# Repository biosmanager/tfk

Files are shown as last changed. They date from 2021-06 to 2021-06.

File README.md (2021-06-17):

# tfk - The F(ine|fancy|inal) Keyboard

This is a work in progress collection of open-source high-end keyboard PCBs. 

**Features**:

-   Compatible with QMK firmware and VIA
-   Hot-swap sockets
-   Per-key RGB lighting and RGB backlight
-   USB-C
-   Overvoltage, overcurrent and ESD protection
-   (All powered by STM32 microcontrollers)

> **NOTE:**  Due to the current global chip crisis I decided to use AVR based microcontrollers in the first revisions which are easier to obtain.

## Keyboards

|Status | Name  | Size | # of keys | Description | MCU | Compatible cases (intended) |
|---| ----- | ---- | --- | ---|-----|---|
| <span style="color: green">Active</span> | tfk21-avr | 20% | 21 | Numpad with extra row | ATmega32U4 | [KPRepublic Cospad cases](https://kprepublic.com/collections/cospad-xd24) |
| <span style="color: red">On hold</span>  | tfk21 | 20% | 21 | Numpad with extra row | STM32F072  | [KPRepublic Cospad cases](https://kprepublic.com/collections/cospad-xd24) |
| <span style="color: red">On hold</span>  | tfk84 | 75% | 84 | More compact than a TKL | STM32F303  | [KPRepublic XD84 cases](https://kprepublic.com/collections/xd84) |

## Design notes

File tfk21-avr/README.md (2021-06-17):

# tfk21-avr

21 key hot-swap RGB numpad with extra row on top. Uses Microchip ATmega32U4-AU microcontroller. 
All footprints should be suitable for hand soldering.

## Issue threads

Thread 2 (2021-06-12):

Update TQFP-48 thermal vias footprint

biosmanager, 2021-06-12:
The default thermal via sizes are too small for JLCPCB.

biosmanager, 2021-06-17:
Not necessary in 4 layer layout.

Closed 2021-06-17.

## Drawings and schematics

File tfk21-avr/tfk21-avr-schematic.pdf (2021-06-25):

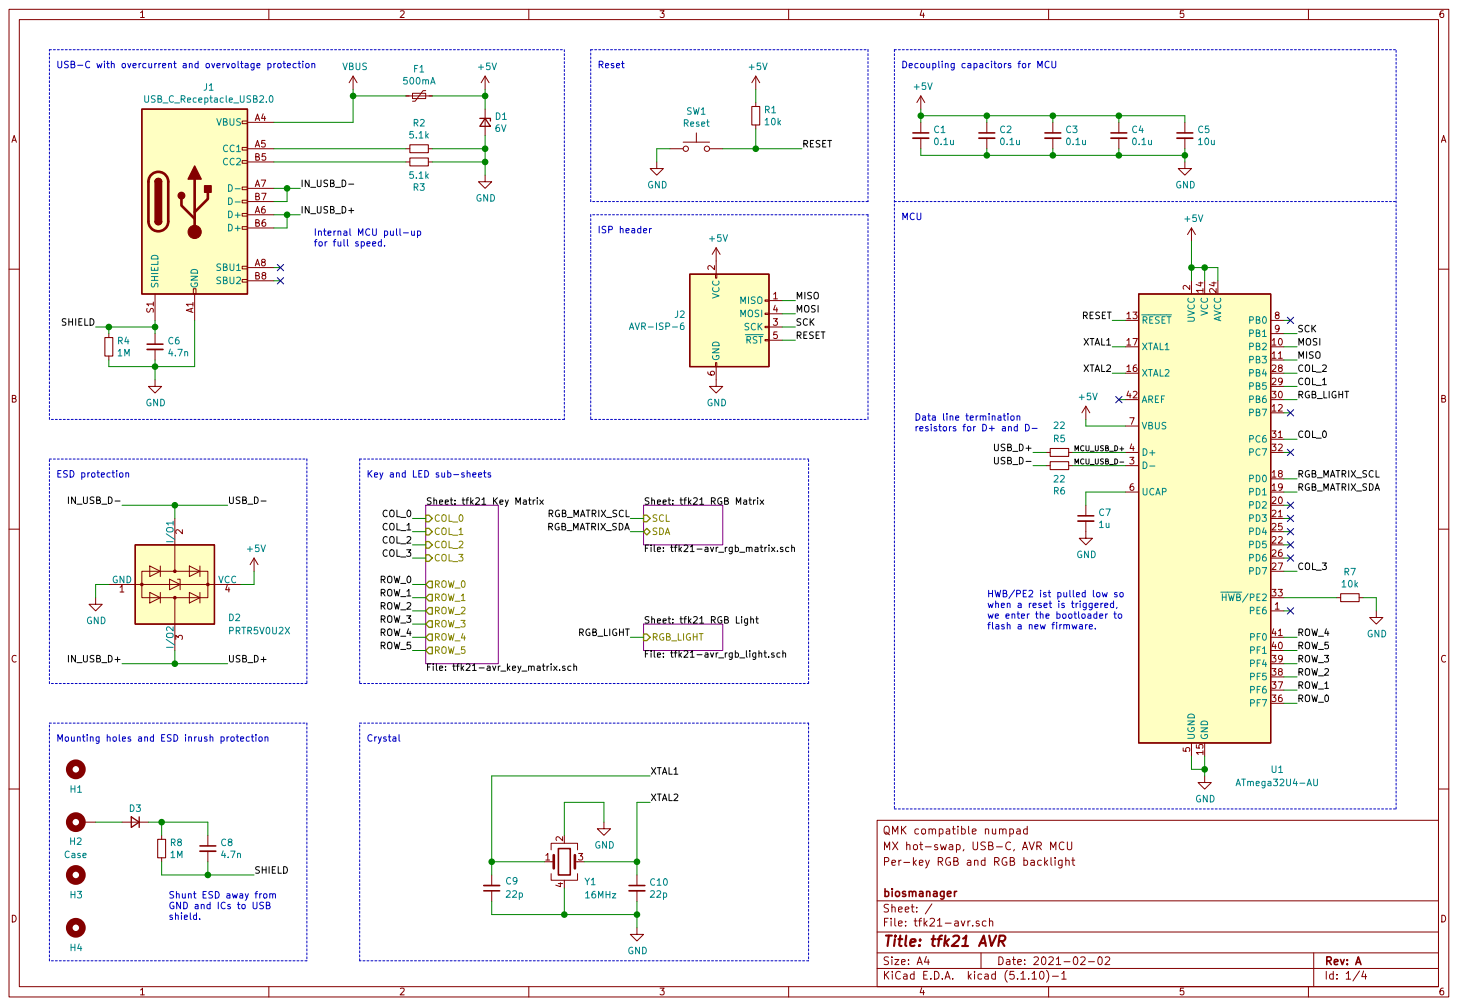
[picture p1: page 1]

USB-C with overcurrent and overvoltage protection

Decoupling capacitors for MCU

Internal MCU pull-up
for full speed.

2 SCK 3 MOSI 4 RST 5 GND

2 PD2 20 PD3 21 PD5 22 AVCC 24 PD4 25 PD6 26 PD7 27 PB4 28 PB5 29 D- 3 PB6 30 PC6 31 PC7 32 HWB/PE2 33 PF7 36 PF6 37 PF5 38 PF4 39 D+ 4 PF1 40 PF0 41 AREF 42 UGND

Key and LED sub-sheets

File: tfk21-avr_rgb_light.sch RGB_LIGHT Sheet: tfk21 Key Matrix

HWB/PE2 ist pulled low so
when a reset is triggered, we enter the bootloader to

QMK compatible numpad
MX hot-swap, USB-C, AVR MCU
Per-key RGB and RGB backlight

File: tfk21-avr.sch Sheet: / biosmanager

Shunt ESD away from GND and ICs to USB shield.

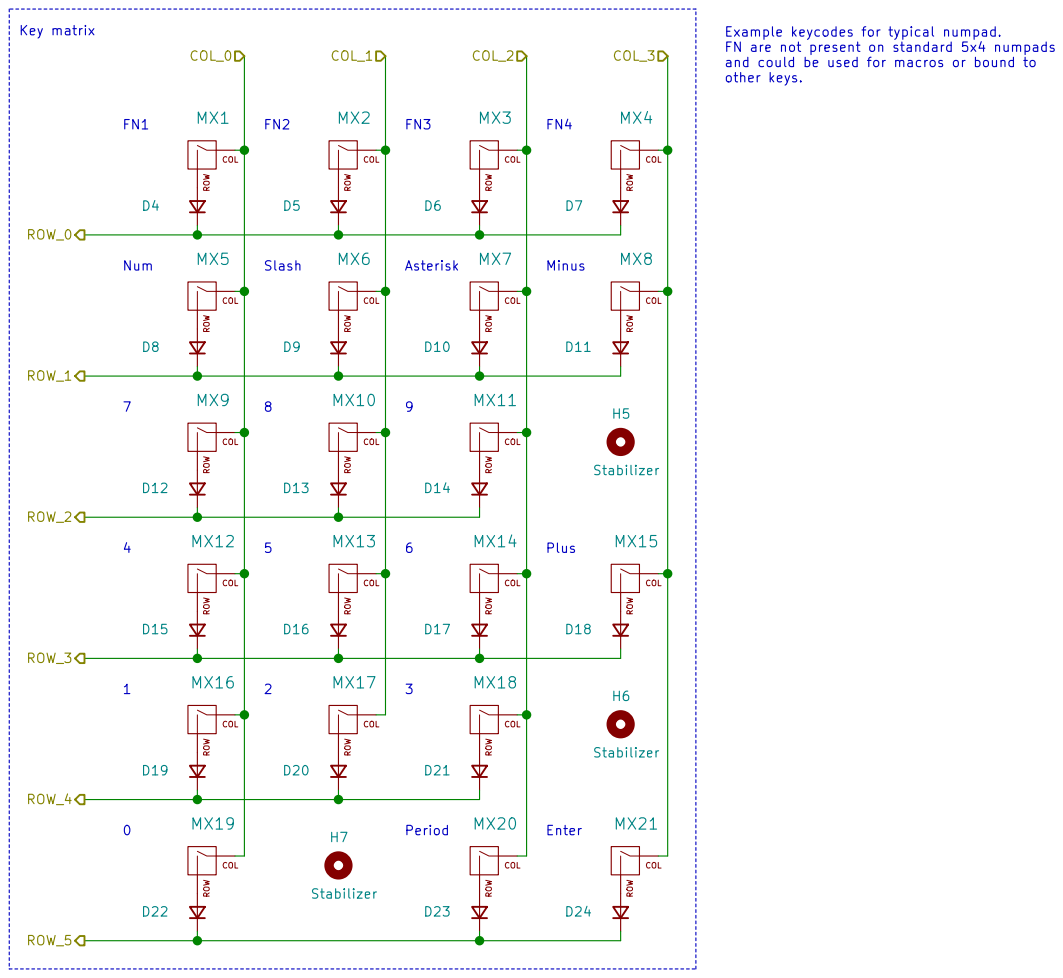
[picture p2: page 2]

Example keycodes for typical numpad.
FN are not present on standard 5x4 numpads and could be used for macros or bound to
COL ROW MX4

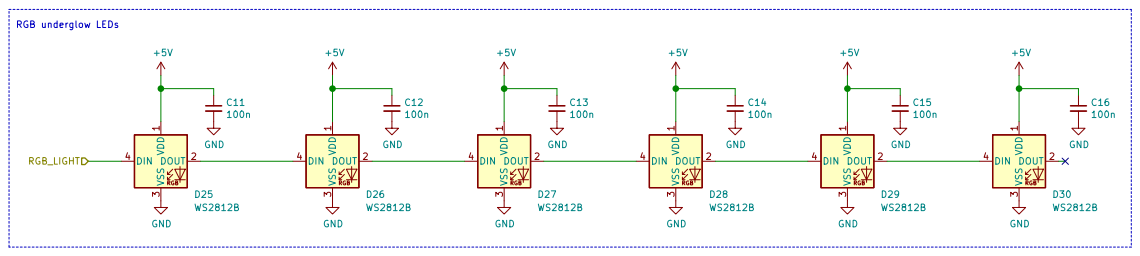
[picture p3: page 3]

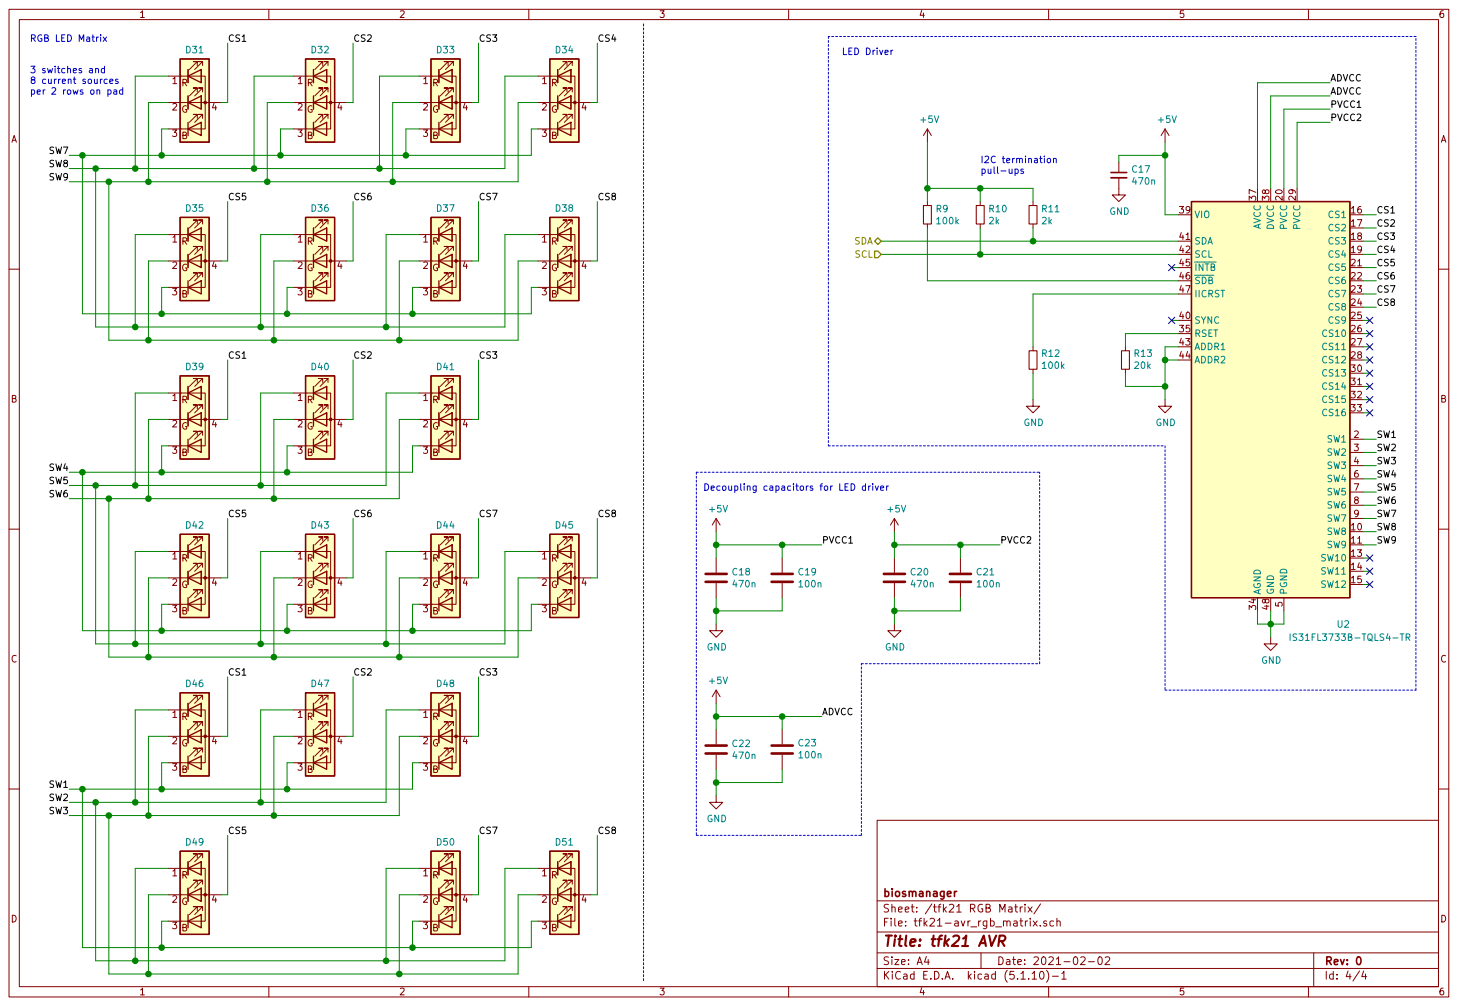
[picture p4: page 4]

LED Driver Decoupling capacitors for LED driver

I2C termination pull-ups 3 switches and
8 current sources per 2 rows on pad

File: tfk21-avr_rgb_matrix.sch Sheet: /tfk21 RGB Matrix/ biosmanager C23

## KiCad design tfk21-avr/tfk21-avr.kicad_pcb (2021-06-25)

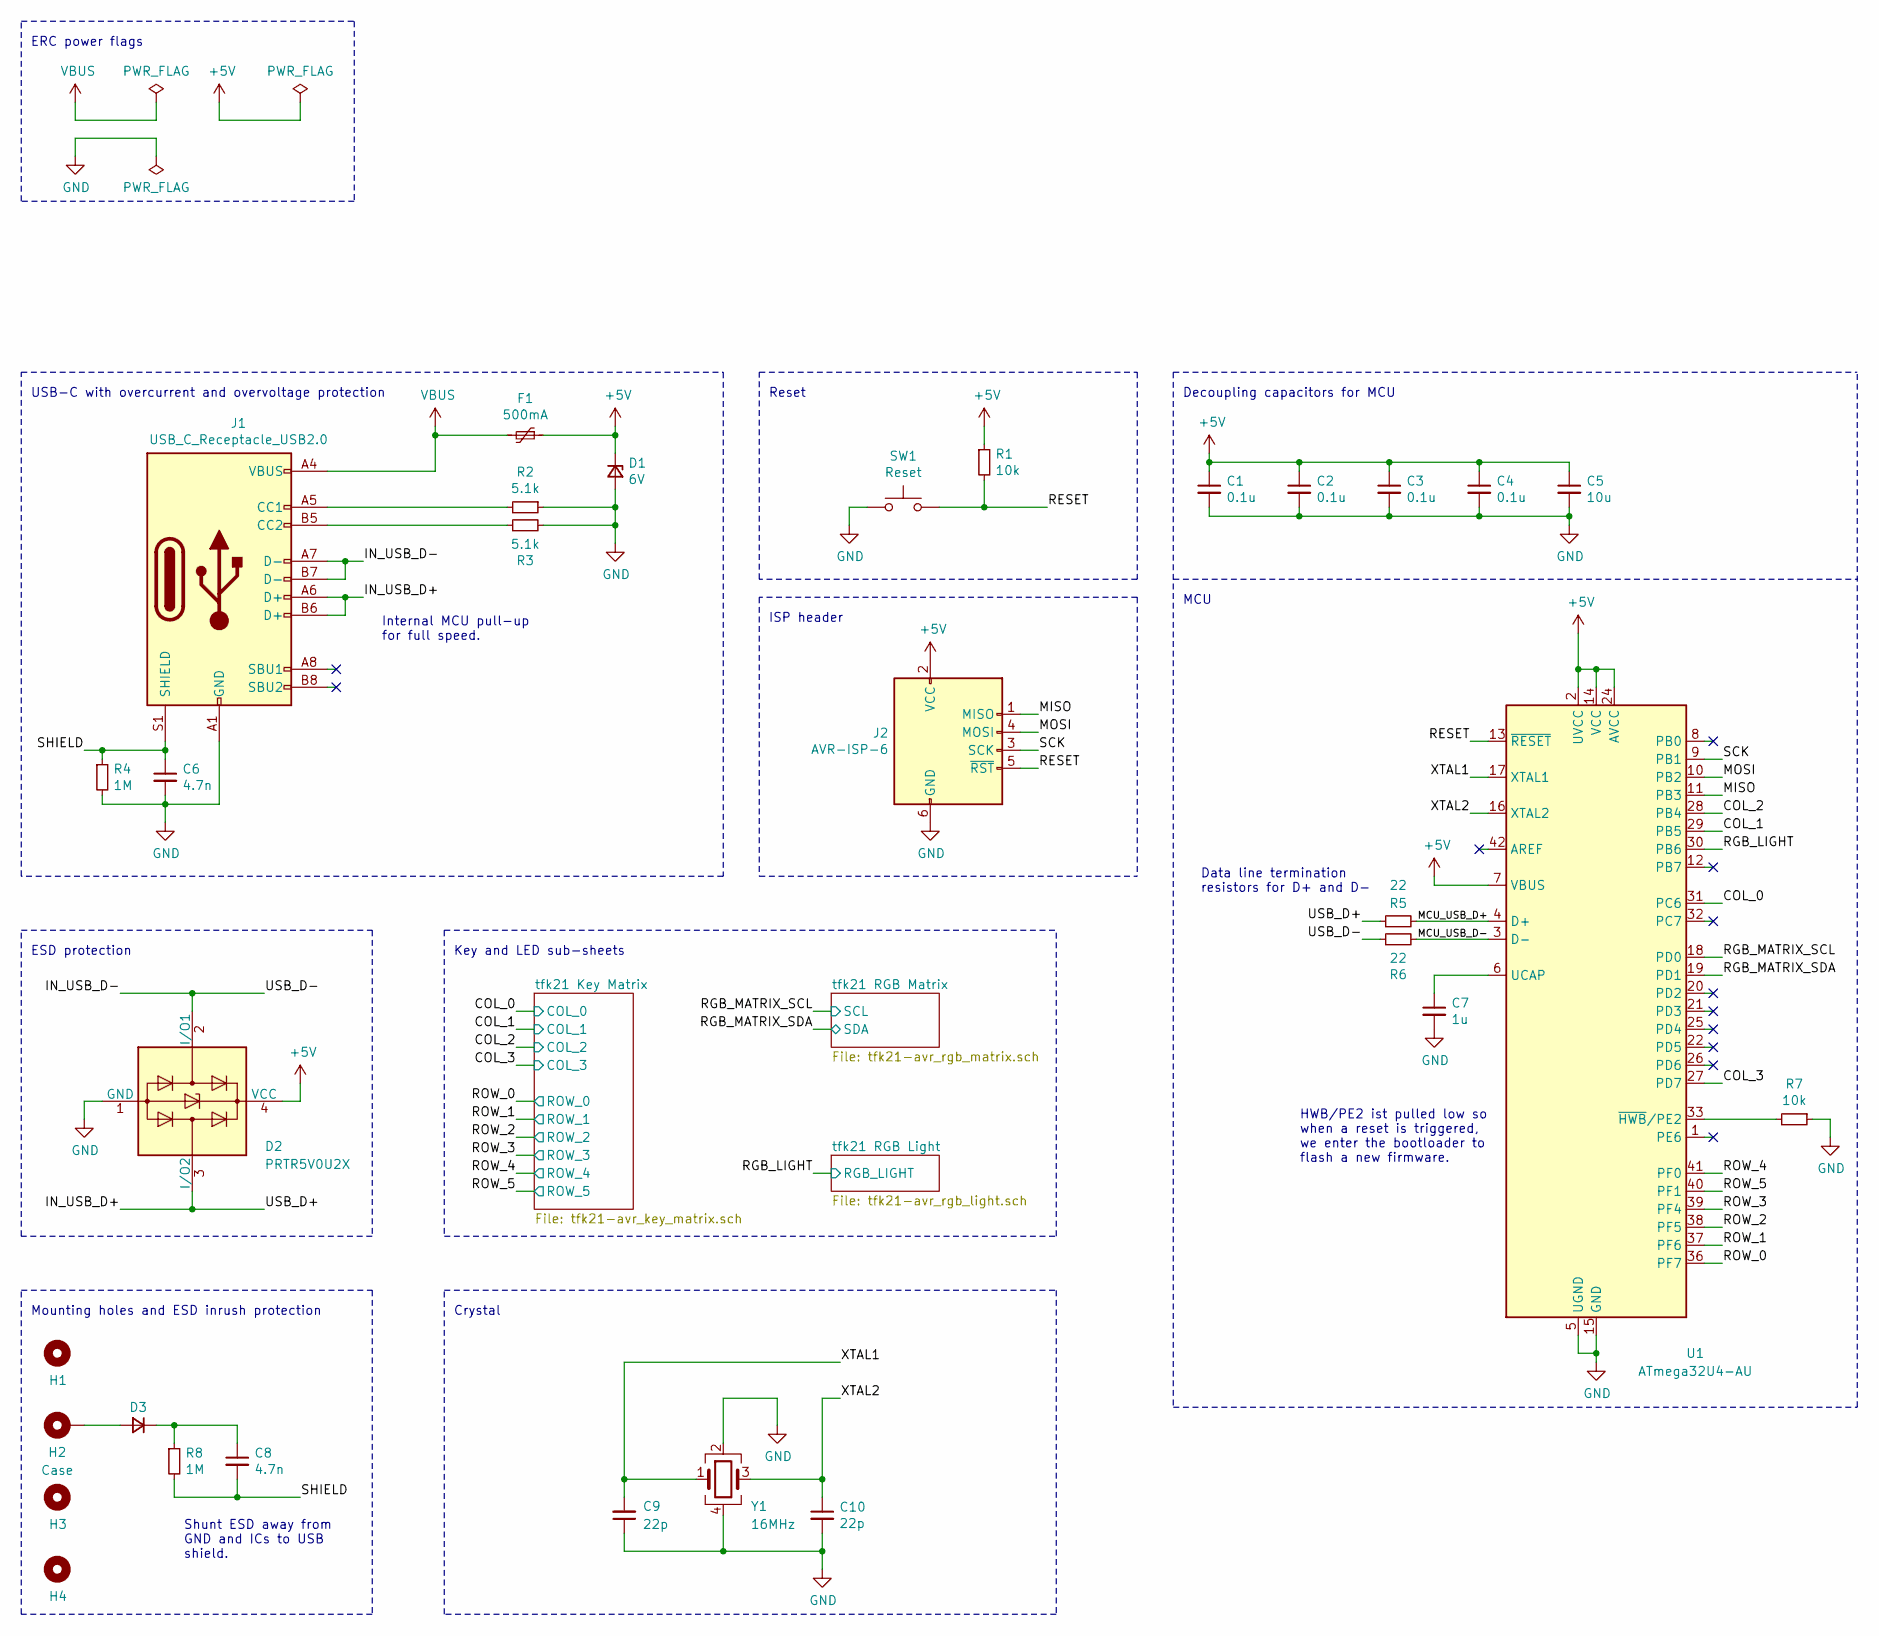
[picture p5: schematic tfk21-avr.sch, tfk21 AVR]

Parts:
C1, C2, C3, C4: 0.1u; C_0805_2012Metric_Pad1.18x1.45mm_HandSolder
C5: 10u; C_0805_2012Metric_Pad1.18x1.45mm_HandSolder
C6, C8: 4.7n; C_0805_2012Metric_Pad1.18x1.45mm_HandSolder
C7: 1u; C_0805_2012Metric_Pad1.18x1.45mm_HandSolder
C9, C10: 22p; C_0805_2012Metric_Pad1.18x1.45mm_HandSolder
D1: 6V; D_SOD-123
D2: PRTR5V0U2X; SOT-143
D3: Case ESD; D_SOD-123
F1: 500mA; Fuse_1206_3216Metric_Pad1.42x1.75mm_HandSolder
H1, H3, H4: MountingHole; MountingHole_2.5mm_Pad
H2: Case; MountingHole_2.5mm_Pad
J1: USB_C_Receptacle_USB2.0; USB_C_Receptacle_HRO_TYPE-C-31-M-12
J2: AVR-ISP-6; Reset_Pretty-Mask
R1, R7: 10k; R_0805_2012Metric_Pad1.20x1.40mm_HandSolder
R2, R3: 5.1k; R_0805_2012Metric_Pad1.20x1.40mm_HandSolder
R4, R8: 1M; R_0805_2012Metric_Pad1.20x1.40mm_HandSolder
R5, R6: 22; R_0805_2012Metric_Pad1.20x1.40mm_HandSolder
SW1: Reset; SKQG-1155865
U1: ATmega32U4-AU; TQFP-44_10x10mm_P0.8mm
Y1: 16MHz; Crystal_SMD_3225-4Pin_3.2x2.5mm_HandSoldering

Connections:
+5V: C1.1, C2.1, C3.1, C4.1, C5.1, D1.1 (K), D2.4 (VCC), F1.1, J2.2 (VCC), R1.1, U1.2 (UVCC), U1.7 (VBUS), U1.14 (VCC), U1.24 (AVCC), U1.34 (VCC), U1.44 (AVCC); also elsewhere on the board
/COL_0: U1.31 (PC6); also elsewhere on the board
/COL_1: U1.29 (PB5); also elsewhere on the board
/COL_2: U1.28 (PB4); also elsewhere on the board
/COL_3: U1.27 (PD7); also elsewhere on the board
/IN_USB_D+: D2.3 (I/O2), J1.A6 (D+), J1.B6 (D+), R5.1
/IN_USB_D-: D2.2 (I/O1), J1.A7 (D-), J1.B7 (D-), R6.1
/MCU_USB_D+: R5.2, U1.4 (D+)
/MCU_USB_D-: R6.2, U1.3 (D-)
/MISO: J2.1 (MISO), U1.11 (PB3)
/MOSI: J2.4 (MOSI), U1.10 (PB2)
/RESET: J2.5 (~RST), R1.2, SW1.2, U1.13 (~RESET)
/RGB_LIGHT: U1.30 (PB6); also elsewhere on the board
/RGB_MATRIX_SCL: U1.18 (PD0); also elsewhere on the board
/RGB_MATRIX_SDA: U1.19 (PD1); also elsewhere on the board
/ROW_0: U1.36 (PF7); also elsewhere on the board
/ROW_1: U1.37 (PF6); also elsewhere on the board
/ROW_2: U1.38 (PF5); also elsewhere on the board
/ROW_3: U1.39 (PF4); also elsewhere on the board
/ROW_4: U1.41 (PF0); also elsewhere on the board
/ROW_5: U1.40 (PF1); also elsewhere on the board
/SCK: J2.3 (SCK), U1.9 (PB1)
/SHIELD: C6.1, C8.2, J1.S1 (SHIELD), R4.1, R8.2
/XTAL1: C9.2, U1.17 (XTAL1), Y1.1
/XTAL2: C10.1, U1.16 (XTAL2), Y1.3
GND: C1.2, C2.2, C3.2, C4.2, C5.2, C6.2, C7.2, C9.1, C10.2, D1.2 (A), D2.1 (GND), J1.A1 (GND), J1.A12 (GND), J1.B1 (GND), J1.B12 (GND), J2.6 (GND), R2.1, R3.2, R4.2, R7.1, SW1.1, U1.5 (UGND), U1.15 (GND), U1.23 (GND), U1.35 (GND), U1.43 (GND), Y1.2, Y1.4; also elsewhere on the board
unnamed: C7.1, U1.6 (UCAP)
unnamed: C8.1, D3.1 (K), R8.1
unnamed: D3.2 (A), H2.1
unnamed: J1.A5 (CC1), R2.2
unnamed: J1.B5 (CC2), R3.1
unnamed: R7.2, U1.33 (~HWB~/PE2)
VBUS: F1.2, J1.A4 (VBUS), J1.A9 (VBUS), J1.B4 (VBUS), J1.B9 (VBUS)

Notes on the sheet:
Internal MCU pull-up for full speed.
Decoupling capacitors for MCU
USB-C with overcurrent and overvoltage protection
Key and LED sub-sheets
ERC power flags
Mounting holes and ESD inrush protection
Shunt ESD away from GND and ICs to USB shield.
Data line termination resistors for D+ and D-
ESD protection
MCU
Crystal
HWB/PE2 ist pulled low so when a reset is triggered, we enter the bootloader to flash a new firmware.
Reset
ISP header

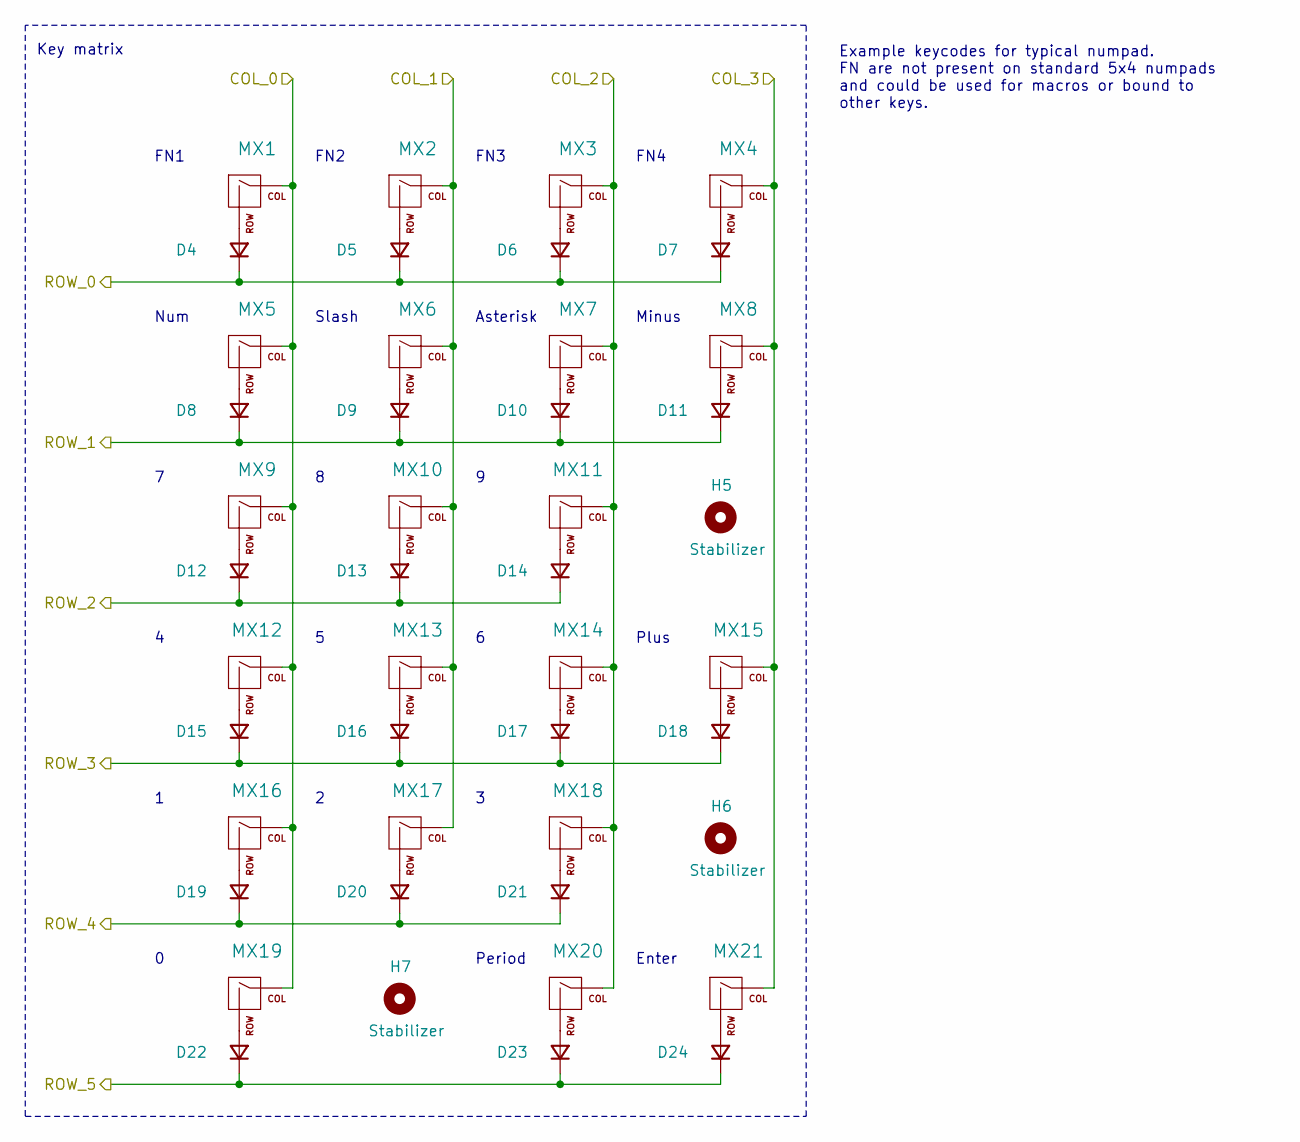
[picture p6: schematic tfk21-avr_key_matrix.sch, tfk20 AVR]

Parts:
D4, D5, D6, D7, D8, D9, D10, D11, D12, D13, D14, D15, D16, D17, D18, D19, D20, D21, D22, D23, D24: Switch diode; D_SOD-123
H5, H6, H7: Stabilizer; Stabilizer_Cherry_MX_2u_CrtYd
MX1, MX2, MX3, MX4, MX5, MX6, MX7, MX8, MX9, MX10, MX11, MX12, MX13, MX14, MX16, MX17, MX18, MX20: MX-NoLED; SW_Hotswap_Kailh_1.00u_NoFrontSilk
MX15, MX19, MX21: MX-NoLED; SW_Hotswap_Kailh_2.00u_NoFrontSilk

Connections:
/COL_0: MX1.1 (COL), MX5.1 (COL), MX9.1 (COL), MX12.1 (COL), MX16.1 (COL), MX19.1 (COL); also elsewhere on the board
/COL_1: MX2.1 (COL), MX6.1 (COL), MX10.1 (COL), MX13.1 (COL), MX17.1 (COL); also elsewhere on the board
/COL_2: MX3.1 (COL), MX7.1 (COL), MX11.1 (COL), MX14.1 (COL), MX18.1 (COL), MX20.1 (COL); also elsewhere on the board
/COL_3: MX4.1 (COL), MX8.1 (COL), MX15.1 (COL), MX21.1 (COL); also elsewhere on the board
/ROW_0: D4.1 (K), D5.1 (K), D6.1 (K), D7.1 (K); also elsewhere on the board
/ROW_1: D8.1 (K), D9.1 (K), D10.1 (K), D11.1 (K); also elsewhere on the board
/ROW_2: D12.1 (K), D13.1 (K), D14.1 (K); also elsewhere on the board
/ROW_3: D15.1 (K), D16.1 (K), D17.1 (K), D18.1 (K); also elsewhere on the board
/ROW_4: D19.1 (K), D20.1 (K), D21.1 (K); also elsewhere on the board
/ROW_5: D22.1 (K), D23.1 (K), D24.1 (K); also elsewhere on the board
unnamed: D4.2 (A), MX1.2 (ROW)
unnamed: D5.2 (A), MX2.2 (ROW)
unnamed: D6.2 (A), MX3.2 (ROW)
unnamed: D7.2 (A), MX4.2 (ROW)
unnamed: D8.2 (A), MX5.2 (ROW)
unnamed: D9.2 (A), MX6.2 (ROW)
unnamed: D10.2 (A), MX7.2 (ROW)
unnamed: D11.2 (A), MX8.2 (ROW)
unnamed: D12.2 (A), MX9.2 (ROW)
unnamed: D13.2 (A), MX10.2 (ROW)
unnamed: D14.2 (A), MX11.2 (ROW)
unnamed: D15.2 (A), MX12.2 (ROW)
unnamed: D16.2 (A), MX13.2 (ROW)
unnamed: D17.2 (A), MX14.2 (ROW)
unnamed: D18.2 (A), MX15.2 (ROW)
unnamed: D19.2 (A), MX16.2 (ROW)
unnamed: D20.2 (A), MX17.2 (ROW)
unnamed: D21.2 (A), MX18.2 (ROW)
unnamed: D22.2 (A), MX19.2 (ROW)
unnamed: D23.2 (A), MX20.2 (ROW)
unnamed: D24.2 (A), MX21.2 (ROW)

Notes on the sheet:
Num
Slash
Asterisk
Minus
Period
Plus
Enter
Key matrix
FN1
FN2
FN3
FN4
Example keycodes for typical numpad. FN are not present on standard 5x4 numpads and could be used for macros or bound to other keys.

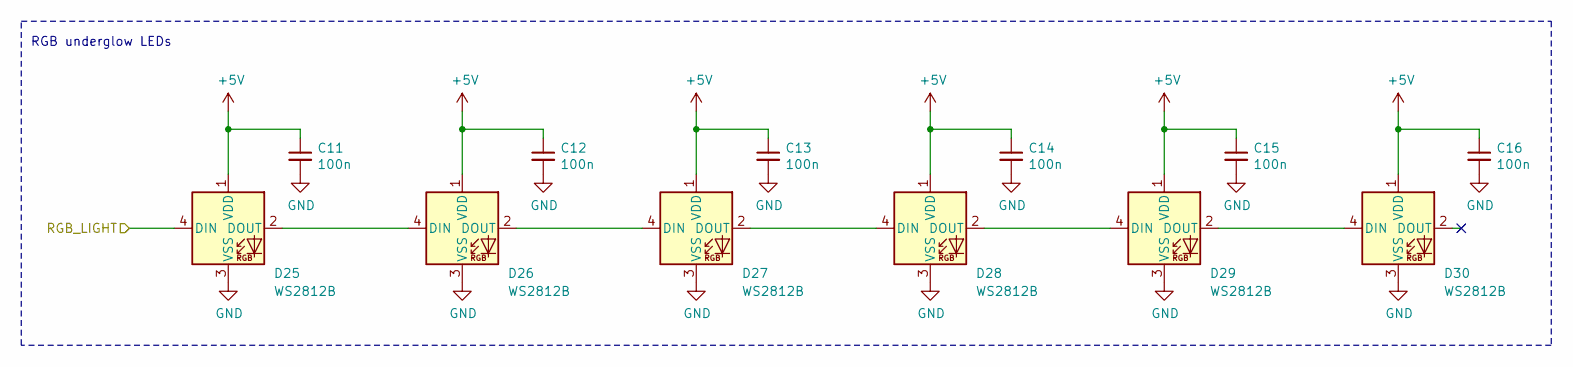
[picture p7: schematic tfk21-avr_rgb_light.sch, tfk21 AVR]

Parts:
C11, C12, C13, C14, C15, C16: 100n; C_0805_2012Metric_Pad1.18x1.45mm_HandSolder
D25, D26, D27, D28, D29, D30: WS2812B; LED_WS2812B_PLCC4_5.0x5.0mm_P3.2mm

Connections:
+5V: C11.1, C12.1, C13.1, C14.1, C15.1, C16.1, D25.1 (VDD), D26.1 (VDD), D27.1 (VDD), D28.1 (VDD), D29.1 (VDD), D30.1 (VDD); also elsewhere on the board
/RGB_LIGHT: D25.4 (DIN); also elsewhere on the board
GND: C11.2, C12.2, C13.2, C14.2, C15.2, C16.2, D25.3 (VSS), D26.3 (VSS), D27.3 (VSS), D28.3 (VSS), D29.3 (VSS), D30.3 (VSS); also elsewhere on the board
unnamed: D25.2 (DOUT), D26.4 (DIN)
unnamed: D26.2 (DOUT), D27.4 (DIN)
unnamed: D27.2 (DOUT), D28.4 (DIN)
unnamed: D28.2 (DOUT), D29.4 (DIN)
unnamed: D29.2 (DOUT), D30.4 (DIN)

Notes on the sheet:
RGB underglow LEDs

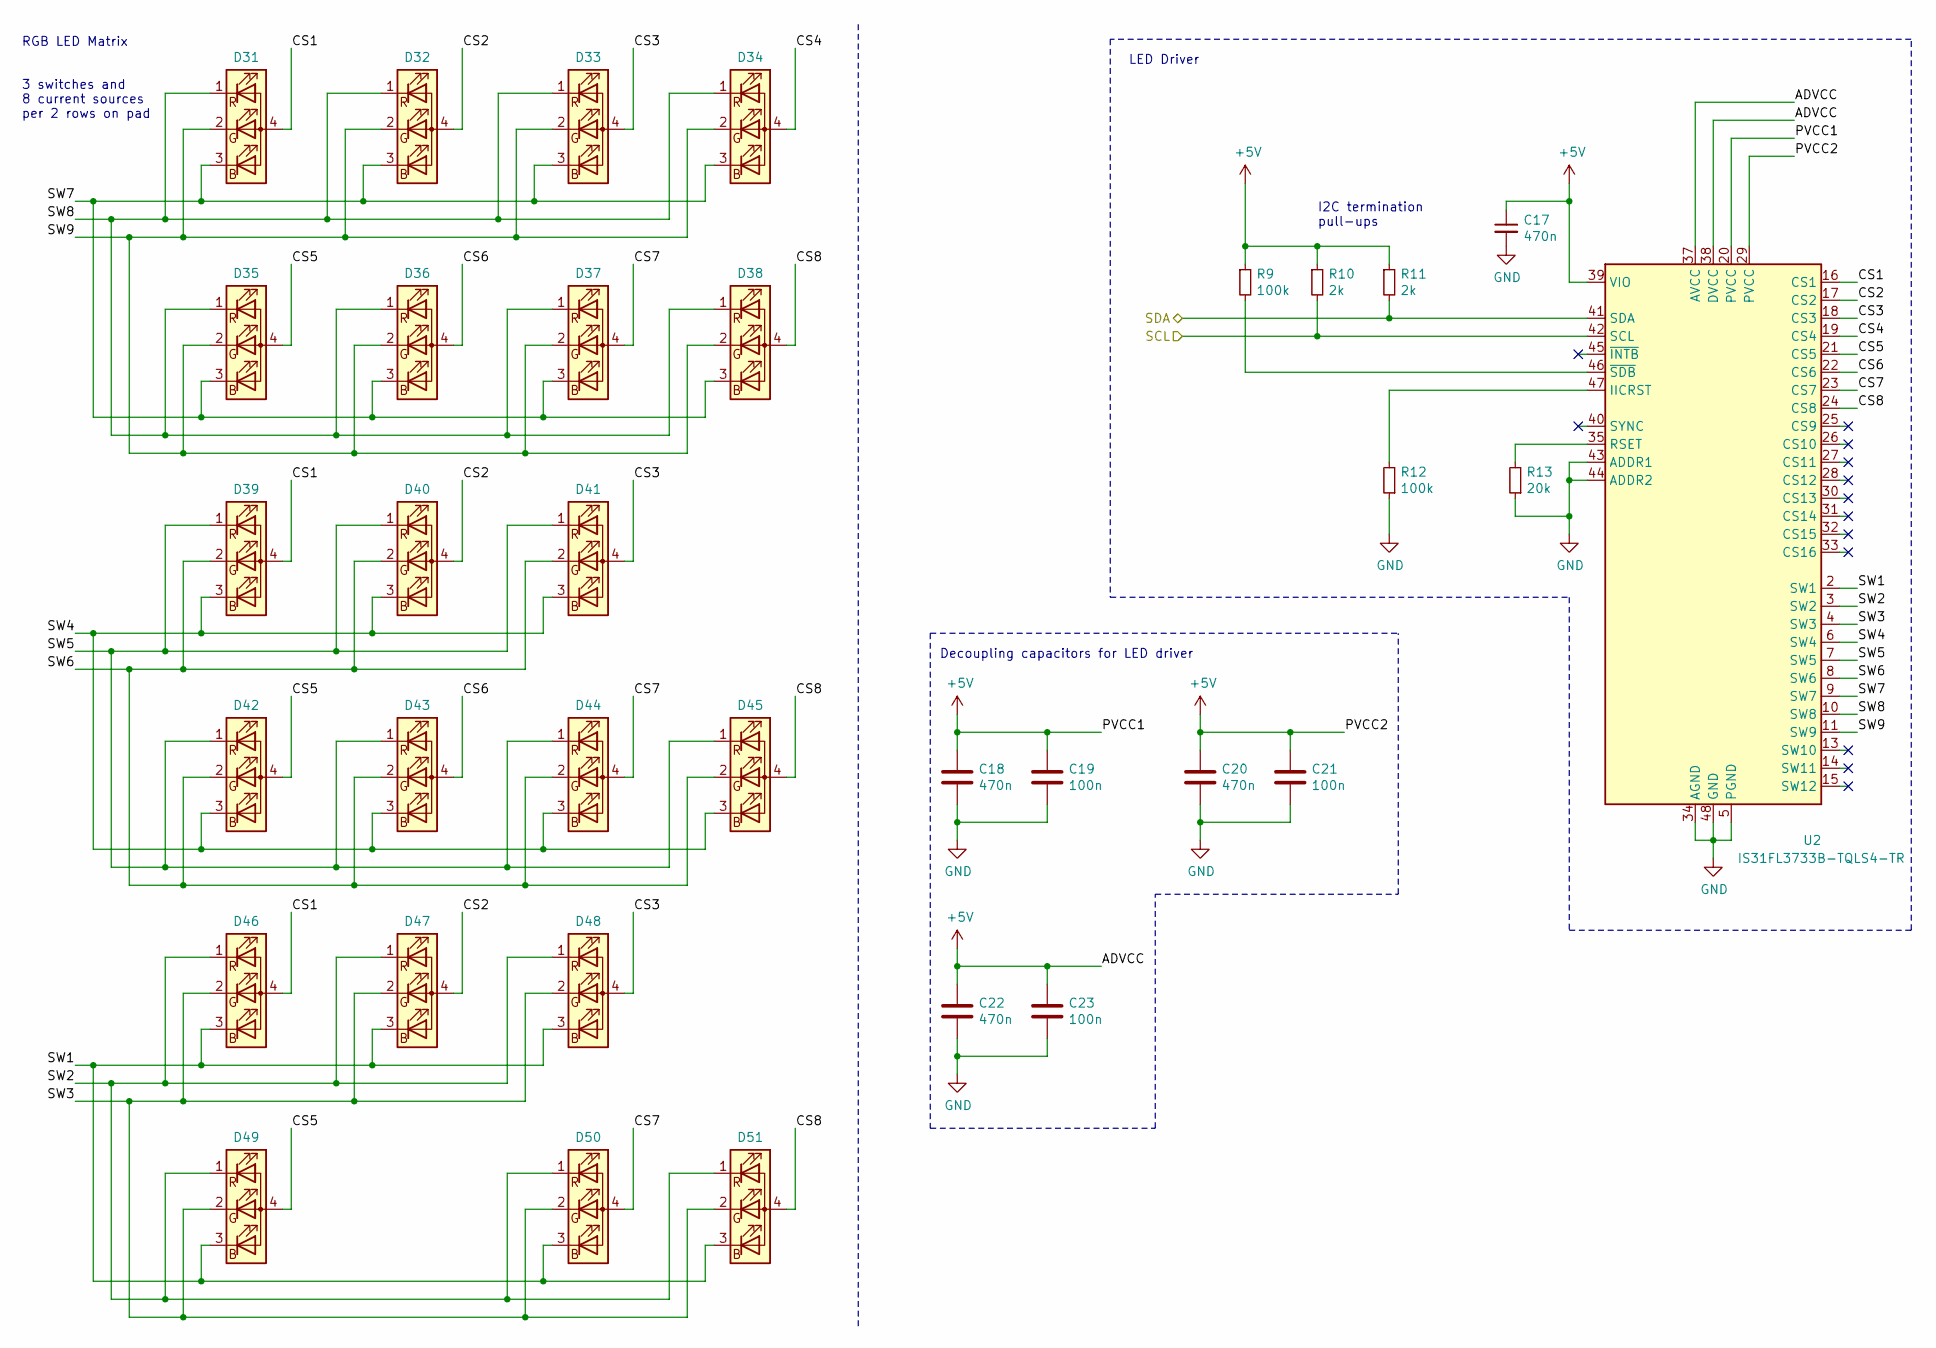
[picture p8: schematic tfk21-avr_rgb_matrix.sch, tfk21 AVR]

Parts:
C17, C18, C20, C22: 470n; C_0805_2012Metric_Pad1.18x1.45mm_HandSolder
C19, C21, C23: 100n; C_0805_2012Metric_Pad1.18x1.45mm_HandSolder
D31, D32, D33, D34, D35, D36, D37, D38, D39, D40, D41, D42, D43, D44, D45, D46, D47, D48, D49, D50, D51: LED_RGBA; RGB-6028
R9, R12: 100k; R_0805_2012Metric_Pad1.20x1.40mm_HandSolder
R10, R11: 2k; R_0805_2012Metric_Pad1.20x1.40mm_HandSolder
R13: 20k; R_0805_2012Metric_Pad1.20x1.40mm_HandSolder
U2: IS31FL3733B-TQLS4-TR; TQFP-48-1EP_7x7mm_P0.5mm_EP5x5mm_ThermalVias

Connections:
+5V: C17.1, C18.1, C19.1, C20.1, C21.1, C22.1, C23.2, R9.1, R10.1, R11.1, U2.20 (PVCC), U2.29 (PVCC), U2.37 (AVCC), U2.38 (DVCC), U2.39 (VIO); also elsewhere on the board
/RGB_MATRIX_SCL: R10.2, U2.42 (SCL); also elsewhere on the board
/RGB_MATRIX_SDA: R11.2, U2.41 (SDA); also elsewhere on the board
/tfk21 RGB Matrix/CS1: D31.4 (A), D39.4 (A), D46.4 (A), U2.16 (CS1)
/tfk21 RGB Matrix/CS2: D32.4 (A), D40.4 (A), D47.4 (A), U2.17 (CS2)
/tfk21 RGB Matrix/CS3: D33.4 (A), D41.4 (A), D48.4 (A), U2.18 (CS3)
/tfk21 RGB Matrix/CS4: D34.4 (A), U2.19 (CS4)
/tfk21 RGB Matrix/CS5: D35.4 (A), D42.4 (A), D49.4 (A), U2.21 (CS5)
/tfk21 RGB Matrix/CS6: D36.4 (A), D43.4 (A), U2.22 (CS6)
/tfk21 RGB Matrix/CS7: D37.4 (A), D44.4 (A), D50.4 (A), U2.23 (CS7)
/tfk21 RGB Matrix/CS8: D38.4 (A), D45.4 (A), D51.4 (A), U2.24 (CS8)
/tfk21 RGB Matrix/SW1: D46.3 (BK), D47.3 (BK), D48.3 (BK), D49.3 (BK), D50.3 (BK), D51.3 (BK), U2.2 (SW1)
/tfk21 RGB Matrix/SW2: D46.1 (RK), D47.1 (RK), D48.1 (RK), D49.1 (RK), D50.1 (RK), D51.1 (RK), U2.3 (SW2)
/tfk21 RGB Matrix/SW3: D46.2 (GK), D47.2 (GK), D48.2 (GK), D49.2 (GK), D50.2 (GK), D51.2 (GK), U2.4 (SW3)
/tfk21 RGB Matrix/SW4: D39.3 (BK), D40.3 (BK), D41.3 (BK), D42.3 (BK), D43.3 (BK), D44.3 (BK), D45.3 (BK), U2.6 (SW4)
/tfk21 RGB Matrix/SW5: D39.1 (RK), D40.1 (RK), D41.1 (RK), D42.1 (RK), D43.1 (RK), D44.1 (RK), D45.1 (RK), U2.7 (SW5)
/tfk21 RGB Matrix/SW6: D39.2 (GK), D40.2 (GK), D41.2 (GK), D42.2 (GK), D43.2 (GK), D44.2 (GK), D45.2 (GK), U2.8 (SW6)
/tfk21 RGB Matrix/SW7: D31.3 (BK), D32.3 (BK), D33.3 (BK), D34.3 (BK), D35.3 (BK), D36.3 (BK), D37.3 (BK), D38.3 (BK), U2.9 (SW7)
/tfk21 RGB Matrix/SW8: D31.1 (RK), D32.1 (RK), D33.1 (RK), D34.1 (RK), D35.1 (RK), D36.1 (RK), D37.1 (RK), D38.1 (RK), U2.10 (SW8)
/tfk21 RGB Matrix/SW9: D31.2 (GK), D32.2 (GK), D33.2 (GK), D34.2 (GK), D35.2 (GK), D36.2 (GK), D37.2 (GK), D38.2 (GK), U2.11 (SW9)
GND: C17.2, C18.2, C19.2, C20.2, C21.2, C22.2, C23.1, R12.1, R13.1, U2.5 (PGND), U2.12 (PGND), U2.34 (AGND), U2.43 (ADDR1), U2.44 (ADDR2), U2.48 (GND), U2.49 (GND); also elsewhere on the board
unnamed: R9.2, U2.46 (~SDB)
unnamed: R12.2, U2.47 (IICRST)
unnamed: R13.2, U2.35 (RSET)

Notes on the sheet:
Decoupling capacitors for LED driver
LED Driver
I2C termination pull-ups
RGB LED Matrix
3 switches and 8 current sources per 2 rows on pad

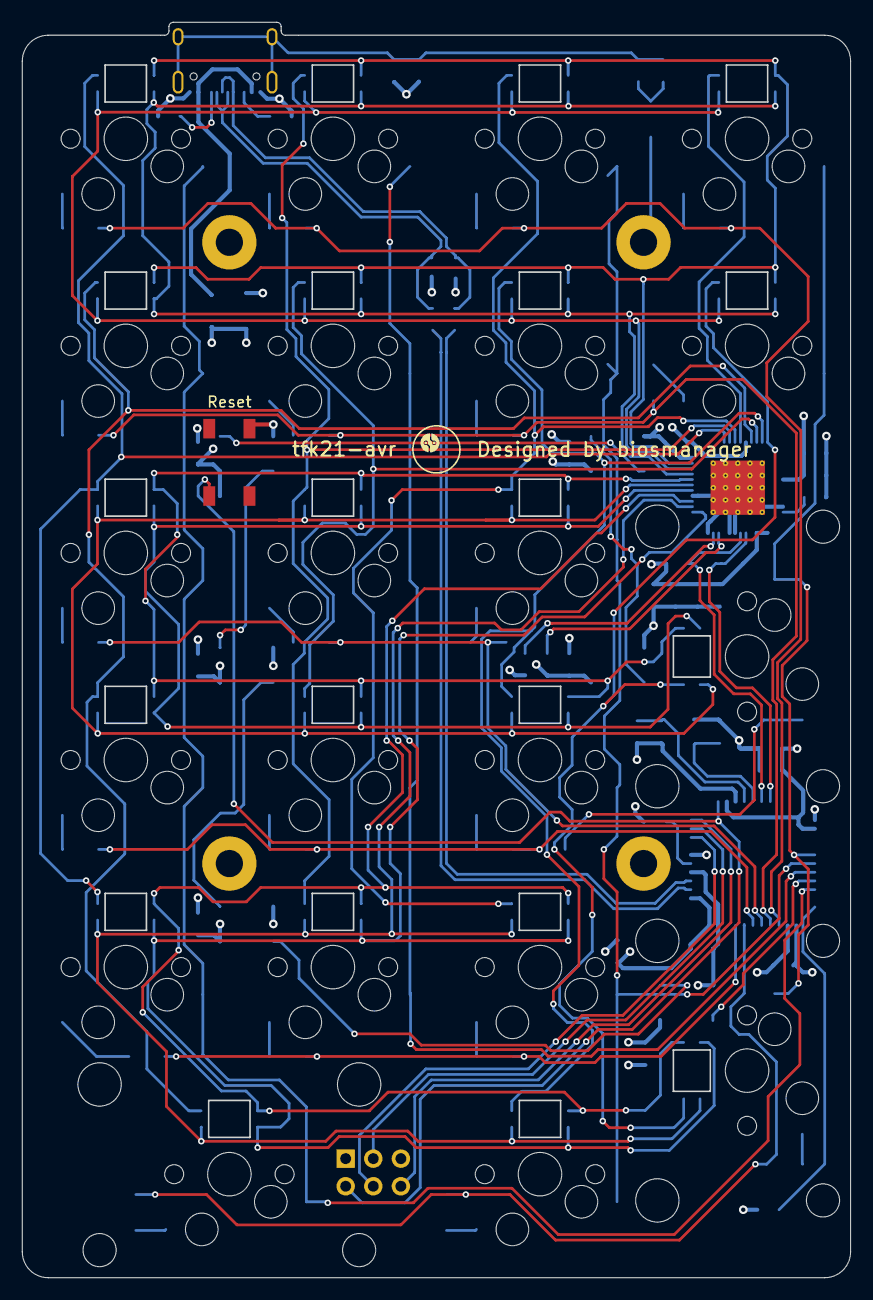
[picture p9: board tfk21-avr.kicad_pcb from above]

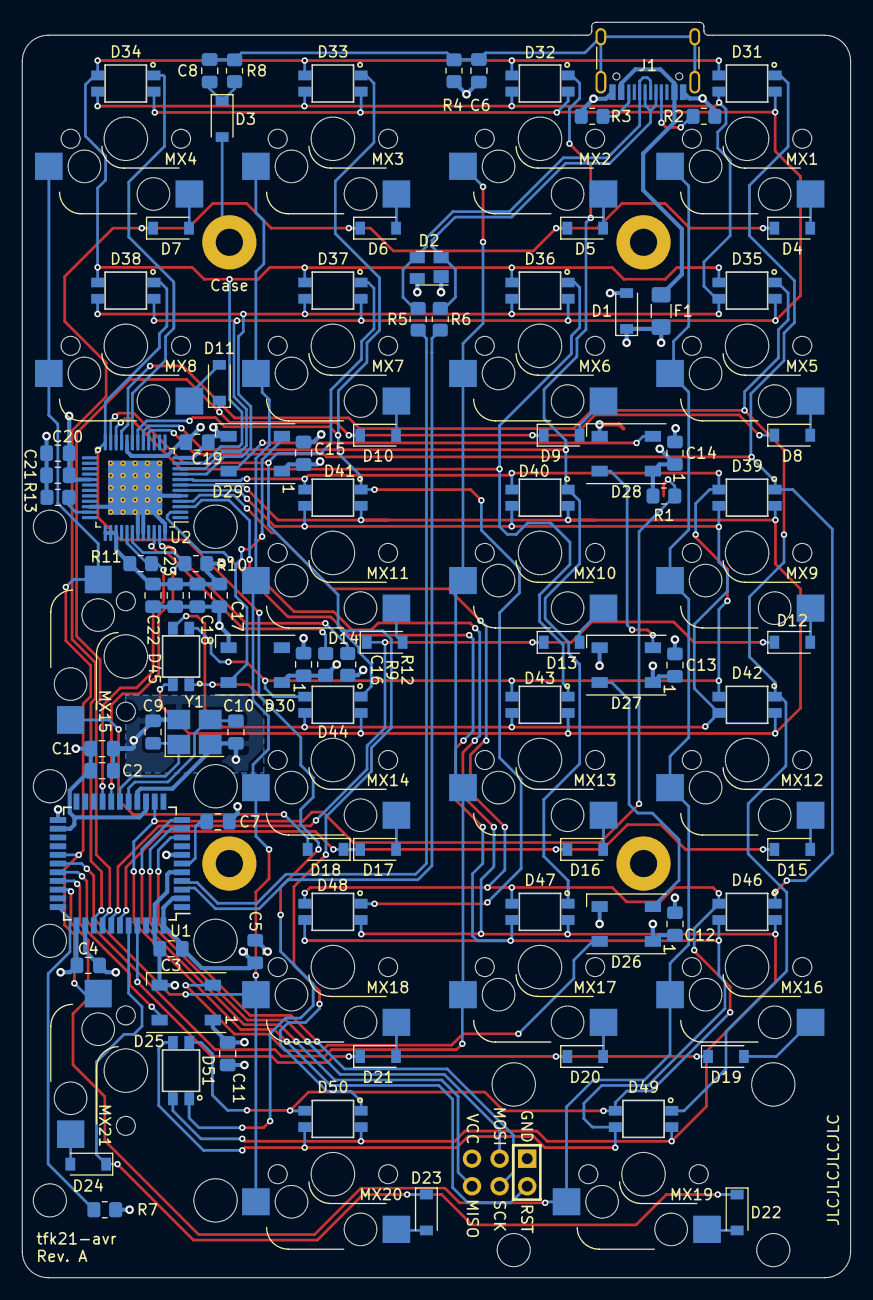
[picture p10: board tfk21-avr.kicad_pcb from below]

Board: 4 copper layers, 76.2 x 115.5 mm, 123 parts (93 on the bottom side), 79 nets.

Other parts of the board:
G1: LOGO; biosmanager_pcb

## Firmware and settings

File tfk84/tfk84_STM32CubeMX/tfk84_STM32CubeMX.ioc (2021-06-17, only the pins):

Mcu.UserName=STM32F303RCTx
PC10.Signal=GPIO_Output
PC12.Signal=GPIO_Output
PB14.GPIO_Label=ROW_5
PC0.GPIO_Label=COL_0
PC6.GPIO_Label=COL_6
PC13.GPIO_Label=COL_13
PB13.GPIO_Label=ROW_4
PB11.Signal=GPIO_Input
PB13.Signal=GPIO_Input
PB15.Signal=GPIO_Input
PA12.Signal=USB_DP
PB6.Signal=I2C1_SCL
PC7.Signal=GPIO_Output
PC3.Signal=GPIO_Output
PB12.GPIO_Label=ROW_3
PC4.GPIO_Label=COL_4
PC11.GPIO_Label=COL_11
PB7.Signal=I2C1_SDA
PB9.Signal=GPIO_Input
PA6.Signal=SPI1_MISO
PA10.Signal=I2C2_SDA
PC14-OSC32_IN.GPIO_Label=COL_14
PC5.Signal=GPIO_Output
PC2.GPIO_Label=COL_2
PF1-OSC_OUT.Signal=RCC_OSC_OUT
PB9.GPIO_Label=ROW_0
PC10.GPIO_Label=COL_10
PC9.GPIO_Label=COL_9
PC11.Signal=GPIO_Output
PC13.Signal=GPIO_Output
PC8.Signal=GPIO_Output
PC2.Signal=GPIO_Output
PC4.Signal=GPIO_Output
PC6.Signal=GPIO_Output
PB11.GPIO_Label=ROW_2
PC0.Signal=GPIO_Output
PC14-OSC32_IN.Signal=GPIO_Output
PC8.GPIO_Label=COL_8
PA13.Signal=SYS_JTMS-SWDIO
PB10.GPIO_Label=ROW_1
PA9.Signal=I2C2_SCL
PB10.Signal=GPIO_Input
PB14.Signal=GPIO_Input
PA5.Signal=SPI1_SCK
PB15.GPIO_Label=ROW_6
PC1.GPIO_Label=COL_1
PC7.GPIO_Label=COL_7
PB3.Signal=SYS_JTDO-TRACESWO
PC5.GPIO_Label=COL_5
PC12.GPIO_Label=COL_12
PA11.Signal=USB_DM
PA14.Signal=SYS_JTCK-SWCLK
PC3.GPIO_Label=COL_3
PC9.Signal=GPIO_Output
PF0-OSC_IN.Signal=RCC_OSC_IN
PC1.Signal=GPIO_Output
PB12.Signal=GPIO_Input
PA7.Signal=SPI1_MOSI

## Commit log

2021-01-10 Initialize tfk75 project
    [tfk75.kicad_pcb, tfk75.sch]
2021-01-16 Add MCU with decoupling caps and linear regulator
    [tfk75.kicad_pcb, tfk75.sch]
2021-01-29 Add key matrix schematic
    [tfk75.sch, tfk75_key_matrix.sch]
2021-01-31 Begin key matrix
    [tfk75.sch, tfk75_key_matrix.sch]
2021-01-31 Finish key matrix, start reset circuit
    [tfk75.sch, tfk75_key_matrix.sch, tfk_rgb_matrix.sch]
2021-02-01 Begin RGB matrix
    [tfk75.sch, tfk75_key_matrix.sch, tfk_rgb_matrix.sch]
2021-02-02 Begin tfk20
    [tfk20.sch, tfk20_key_matrix.sch, tfk20_rgb_light.sch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]
2021-02-04 Continue on tfk20
    [tfk20.sch, tfk20_key_matrix.sch, tfk20_rgb_light.sch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]
2021-02-07 RGB LED driver
    [tfk20.sch, tfk20_rgb_light.sch, tfk20_rgb_matrix.sch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]
2021-02-08 Change caps layout
    [tfk20.sch, tfk20_rgb_matrix.sch]
2021-02-18 Change MCU, add another row, add reset button
    [tfk20.sch, tfk20_key_matrix.sch, tfk20_rgb_light.sch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]
2021-03-01 Implement sophisticated USB-C protection
    [tfk20.sch, tfk20_key_matrix.sch, tfk20_regulator_usb_protection.sch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]
2021-03-05 Add STL11N3LLH6 footprint
    [tfk20.sch, tfk20_key_matrix.sch, tfk20_regulator_usb_protection.sch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]
2021-03-14 Fix project
    [tfk20.sch, tfk20_regulator_usb_protection.sch]
2021-06-04 Implement tfk20 AVR schematic
    [tfk20-avr.sch, tfk20_key_matrix.sch, tfk20_regulator_usb_protection.sch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]
2021-06-04 Set AVR suffix consistently
    [tfk20-avr.sch, tfk20-avr_key_matrix.sch, tfk20-avr_rgb_light.sch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]
2021-06-05 Add mounting holes
    [tfk20-avr.sch, tfk20-avr_key_matrix.sch, tfk20-avr_rgb_matrix.sch]
2021-06-05 Remove alternative switch positions
    [tfk20-avr.sch, tfk20-avr_key_matrix.sch]
2021-06-06 Add ISP header
    [tfk20-avr.sch, tfk20-avr_key_matrix.sch, tfk20-avr_rgb_light.sch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]
2021-06-06 Assign some footprints
    [tfk20-avr.sch, tfk20-avr_key_matrix.sch, tfk20-avr_rgb_light.sch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]
2021-06-06 Remove alternative LEDs
    [tfk20-avr_key_matrix.sch, tfk20-avr_rgb_matrix.sch]
2021-06-06 Assigned remaining footprints
    [tfk20-avr.sch, tfk20-avr_rgb_matrix.sch]
2021-06-06 Begin PCB
    [tfk20-avr.kicad_pcb, tfk20-avr.sch, tfk20-avr_rgb_matrix.sch]
2021-06-07 Place all footprints on PCB
    [tfk20-avr.kicad_pcb, tfk20-avr_rgb_light.sch]
2021-06-07 Fix clearance and courtyard issues
    [tfk20-avr.kicad_pcb]
2021-06-08 Begin north-facing LED layout
    [tfk20-avr.kicad_pcb, tfk20-avr_key_matrix.sch]
2021-06-09 Finish north-facing LED footprint layout
    [tfk20-avr.kicad_pcb, tfk20-avr.sch]
2021-06-10 Continue routing
    [tfk20-avr.kicad_pcb, tfk20-avr.sch]
2021-06-12 Finish routing
    [tfk20-avr.kicad_pcb]
2021-06-12 Add dimensions
    [tfk20-avr.kicad_pcb]
2021-06-12 Tweak some things
    [tfk20-avr-B_Cu.gbr, tfk20-avr-B_Mask.gbr, tfk20-avr-B_Paste.gbr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]
2021-06-12 Add signature
    [tfk20-avr-B_Cu.gbr, tfk20-avr-B_Mask.gbr, tfk20-avr-B_Paste.gbr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]
2021-06-14 Start new 4 layer layout
    [tfk20-avr.kicad_pcb]
2021-06-14 Route VBUS
    [tfk20-avr.kicad_pcb]
2021-06-15 Route PWR and GND
    [tfk20-avr.kicad_pcb, tfk20-avr_key_matrix.sch]
2021-06-15 Route columns
    [tfk20-avr.kicad_pcb]
2021-06-16 Tweak some routes
    [tfk20-avr.kicad_pcb]
2021-06-17 Fix silkscreen
    [tfk20-avr.kicad_pcb]
2021-06-17 Place OVP diode after fuse
    [tfk20-avr.kicad_pcb, tfk20-avr.sch]
2021-06-17 Clean up
    [tfk20-avr.kicad_pcb, tfk20-avr_rgb_matrix.sch]
2021-06-17 Tweak silk screen
    [tfk20-avr.kicad_pcb, tfk20-avr_key_matrix.sch]
2021-06-17 Rename tfk20 and tfk75
    [tfk21.sch, tfk21_key_matrix.sch, tfk21_regulator_usb_protection.sch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]
2021-06-18 Add 3D models
    [tfk21-avr.kicad_pcb]
2021-06-19 Add more dimensions
    [tfk21-avr.kicad_pcb]
2021-06-19 Tweak position of C5 to allow more space for stabilizer
    [tfk21-avr.kicad_pcb]
2021-06-20 Fix LED driver resistors and mounting hole pads
    [tfk21-avr.kicad_pcb, tfk21-avr_rgb_matrix.sch]
2021-06-20 Use newer revision of LED driver
    [tfk21-avr_rgb_matrix.sch]
2021-06-24 Add dimension
    [tfk21-avr.kicad_pcb]
2021-06-24 Add location of JLCPCB order number
    [tfk21-avr.kicad_pcb]
2021-06-24 Set plot settings for JLCPCB
    [tfk21-avr.kicad_pcb]
2021-06-24 Hide silkscreen graphic lines
    [tfk21-avr.kicad_pcb]
2021-06-24 Plot values in Gerbers
    [tfk21-avr.kicad_pcb]
2021-06-25 Tweak component values
    [tfk21-avr.kicad_pcb, tfk21-avr.sch, tfk21-avr_rgb_light.sch]
2021-06-25 Add Gerber files, BOM and schematic PDF
    [tfk21-avr-B_Cu.gbl, tfk21-avr-B_Mask.gbs, tfk21-avr-B_Paste.gbp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]
